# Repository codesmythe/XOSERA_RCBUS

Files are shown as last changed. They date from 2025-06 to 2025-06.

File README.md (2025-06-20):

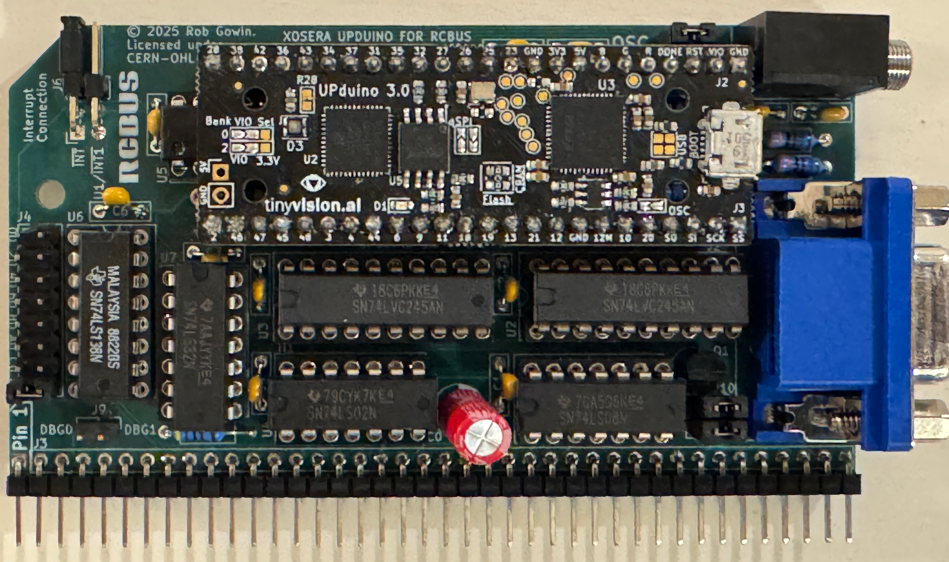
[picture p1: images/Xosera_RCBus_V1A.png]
Xosera RCBus V1A


[Xosera](https://github.com/XarkLabs/Xosera) is an FPGA based "retro"
graphics adapter created by @Xark.  Check out the link to see all of
its features (which are summarized in the image below). Xosera was
originally designed for the rosco_m68k single board computer and the
bus interface for that board. But, Xosera features a simple 8-bit data
bus with a few control signals.  So, this project is a "port" of
Xosera to the [RCBus](https://smallcomputercentral.com/rcbus/) bus
interface. 

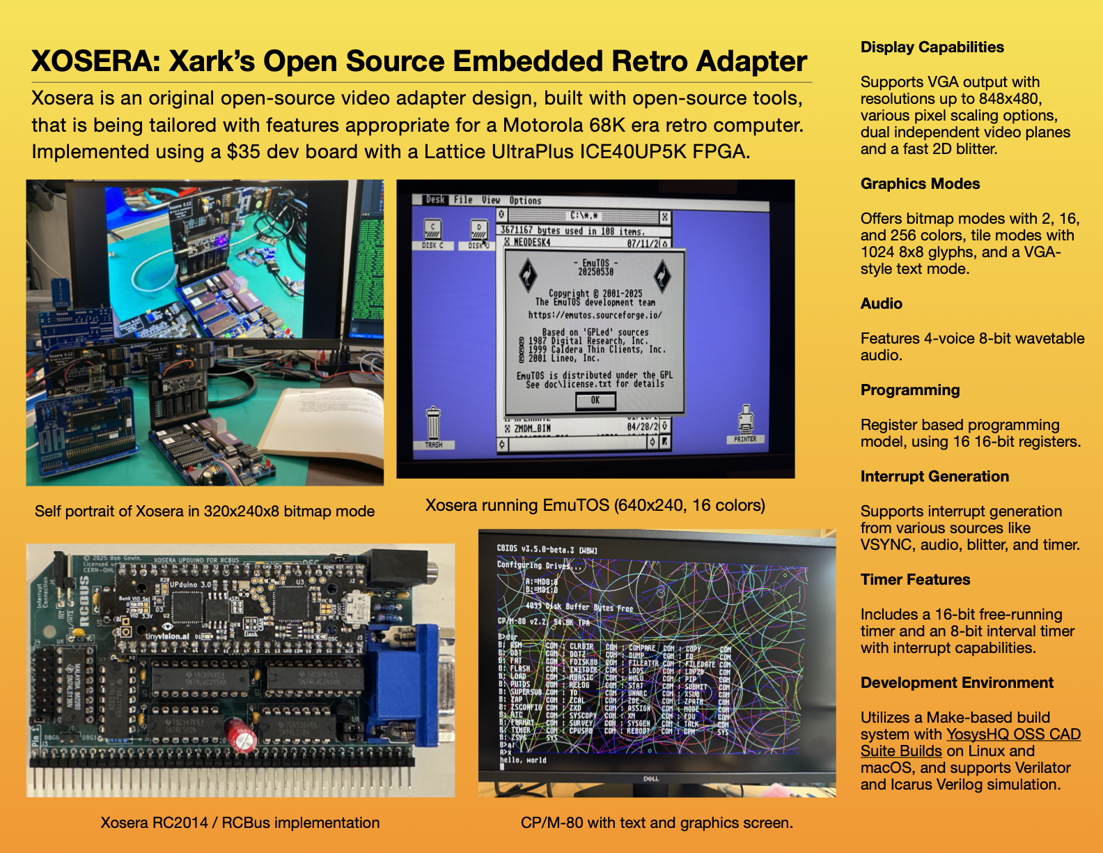
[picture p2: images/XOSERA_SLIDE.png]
Xosera Slide


## Table of Contents
* [Hardware Documentation](#hardware-documentation)
  * [Schematic](#schematic)
  * [Connectors](#connectors)
  * [Jumpers](#jumpers)
  * [Bill of Materials](#bill-of-materials)
* [Programming the FPGA](#progamming-the-fpga)
* [Acknowledgements](#acknowledgements)

## Hardware Documentation

### Schematic

This four layer board was created using [Kicad](https://www.kicad.org) version 8.0.

Click the image below to download a PDF version of the schematic.

Schematic

### Connectors

| Reference | Comment |
| --- | --- |
| J3 | 40-pin RCBus connector |
| J5 | Female VGA monitor connector |
| J11 | Audio Jack |

### Jumpers

| Reference | | Description | Comment |
| --- | --- | --- | --- |
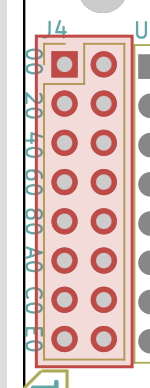
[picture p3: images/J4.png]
J4
| J4 |  | I/O Address decode | The J4 jumper block controls where in the Z80 I/O space the XOSERA_RCBUS board will appear. The Xosera interface requires 32 bytes of I/O addresses, and can be configured to appear at I/O addresses 0x00-0x1F, 0x20-0x3F, 0x40-0x5F, 0x60-0x7F, 0x80-0x9F, 0xA0-0xBF, 0xC0-0xDF or 0xE0-0xFF |
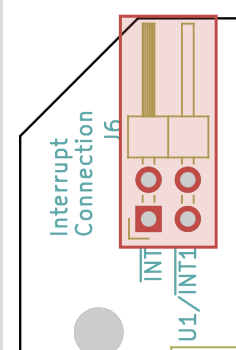
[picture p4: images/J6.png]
J6
| J6 |  | Interrupt connection to RCBus | The board can generate a single interrupt Xosera. Jumper the left two pins of J6 to use the /INT RCBus signal (pin 22) or the right two pins to use the RCBus USER1/INT1 signal (pin 37). |
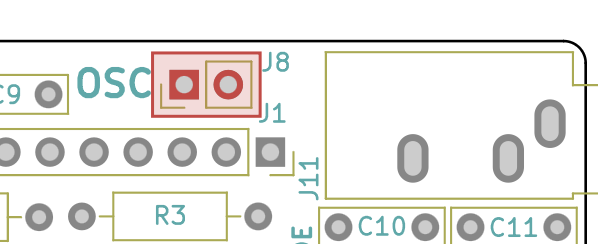
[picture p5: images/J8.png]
J8
| J8 |  | Upduino clock | This jumper must be closed for proper operation. |
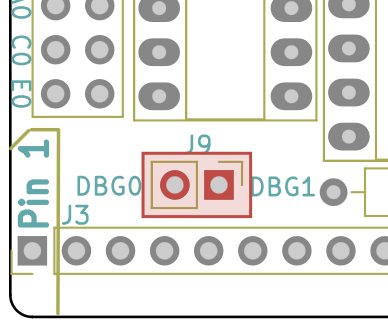
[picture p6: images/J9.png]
J9
| J9 |  | Xosera debug pin | Leave this jumper open under normal operation. |
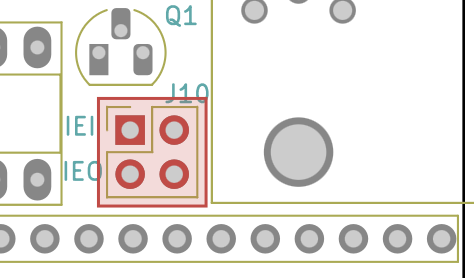
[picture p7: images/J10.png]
J10
| J10 |  | IEI/IEO signals. | Add two horizontal jumpers. These jumpers connect the XOSERA_RCBUS board to the RCBus system IEI/IEO  signals. Normally required. |

The default I/O address setting for this board is 0xA0.

## Bill of Materials (BOM)

[Text file parts list](XOSERA_RCBUS_mouser.txt) for pasting into the [Mouser BOM tool](https://www.mouser.com/Bom/CopyPaste) (login required).

Check out the [interactive BOM](https://htmlpreview.github.io/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)
for the board.

To obtain a KEMOJO PCB, download these [Gerbers](https://raw.githubusercontent.com/codesmythe/XOSERA_RCBUS/refs/heads/main/XOSERA_RCBUS_V1A.zip) for use at your preferred PCB manufacturer. I use JLCPCB.

| Component Type | Reference | Qty | Description | Part |
| --- | --- | --- | --- | --- |
| FPGA Dev Board | (Plugs into J1 & J2) | 1 | Upduino 3.1 low cost Lattice iCE40 FPGA board | Purchase from [TinyVision.ai](https://tinyvision.ai/products/fpga-development-board-upduino-v3-1) or [Tindie](https://www.tindie.com/products/tinyvision_ai/upduino-v31-low-cost-lattice-ice40-fpga-board/?pt=ac_prod_search) |
| Capacitor | C0 | 1 | 47uF, Electrolytic, 2.5mm Pitch | Mouser [710-860020673013](https://www.mouser.com/ProductDetail/710-860020673013) |
| Capacitor | C1-C9 | 9 | 0.1 uF, MLCC, 5 mm Pitch | Mouser [594-K104K15X7RF5TH5](https://www.mouser.com/ProductDetail/594-K104K15X7RF5TH5) |
| Capacitor | C10,C11 | 2 | 4700pF, MLCC, 5 mm Pitch | Mouser [594-K472K10X7RF5UH5](https://www.mouser.com/ProductDetail/594-K472K10X7RF5UH5) |
| Diode | D1 | 1 | 1N5817 | Mouser [511-1N5817](https://www.mouser.com/ProductDetail/511-1N5817) |
| Socket | J1,J2 | 2 | 1x24 female pin socket | Mouser [517-929850-01-26-RA](https://www.mouser.com/ProductDetail/517-929850-01-26-RA) |
| Connector | J3 | 1 | 1x40 right angle pin header | Mouser [710-61304011021](https://www.mouser.com/ProductDetail/710-61304011021) |
| Jumper Block | J4 | 1 | 2x8 straight pin header | Mouser [200-TSW10807TD](https://www.mouser.com/ProductDetail/200-TSW10807TD) |
| Connector | J5 | 1 | Female VGA connector | Mouser [523-7HDE15SD1CH4FVGA](https://www.mouser.com/ProductDetail/523-7HDE15SD1CH4FVGA) |
| Jumper Block | J6 | 1 | 2x2 right angle pin header | Mouser [710-61300421021](https://www.mouser.com/ProductDetail/710-61300421021) |
| Jumper | J8,J9 | 2 | 1x2 straight pin header | Mouser [571-5-146268-1](https://www.mouser.com/ProductDetail/571-5-146268-1) |
| Jumper Block | J10 | 1 | 2x2 straight pin header | Mouser [737-PH2-04-UA](https://www.mouser.com/ProductDetail/737-PH2-04-UA) |
| Connector | J11 | 1 | 3-pin Audio Jack, no switches | Mouser [SJ1-3533NG](https://www.mouser.com/ProductDetail/SJ1-3533NG) |
| Transistor | Q1 | 1 | 2N7000  MOSFET in TO92 | Mouser [512-2N7000](https://www.mouser.com/ProductDetail/512-2N7000) |
| Resistor | R1,R2,R3 | 3 | 470 ohm, axial, 1% tolerance, 1/4 W | Mouser [603-MFR-25FTF52-470R](https://www.mouser.com/ProductDetail/603-MFR-25FTF52-470R) |
| Resistor | R4,R5,R6 | 3 | 1K ohm, axial, 1% tolerance, 1/4 W | Mouser [603-MFR-25FTF52-1K](https://www.mouser.com/ProductDetail/603-MFR-25FTF52-1K) |
| Resistor | R7,R8,R9 | 3 | 2.2K ohm, axial, 1% tolerance, 1/4 W | Mouser [603-MFR-25FTF52-2K2](https://www.mouser.com/ProductDetail/603-MFR-25FTF52-2K2) |
| Resistor | R10,R11 | 2 | 47 ohm, axial, 1% tolerance, 1/4 W | Mouser [603-MFR-25FTF52-47R](https://www.mouser.com/ProductDetail/603-MFR-25FTF52-47R) |
| Resistor | R12,R13,R14,R17 |  4 | 4.7K ohm, axial, 1% tolerance, 1/4 W | Mouser [603-MFR-25FTF52-4K7](https://www.mouser.com/ProductDetail/603-MFR-25FTF52-4K7) |
| Resistor | R15,R16 | 2 | 3.3K ohm, axial, 1% tolerance, 1/4 W | Mouser [603-MFR-25FRF52-3K3](https://www.mouser.com/ProductDetail/603-MFR-25FRF52-3K3) |
| Integrated Circuit | U1 | 1 | 74LS08 quad 2-input AND in 14-pin DIP | Mouser [595-SN74LS08N](https://www.mouser.com/ProductDetail/595-SN74LS08N) |
| Integrated Circuit | U2,U3 | 2 | 74LVC245 octal bus transceiver in 20-pin DIP | Mouser [595-SN74LVC245ANE4](https://www.mouser.com/ProductDetail/595-SN74LVC245ANE4) |
| Integrated Circuit | U4 | 1 | 74LS02 quad 2-pin NOR in 14-pin DIP | Mouser [595-SN74LS02N](https://www.mouser.com/ProductDetail/595-SN74LS02N) |
| Integrated Circuit | U5 | 1 | 74LS74 dual D flip flops in 14-pin DIP | Mouser [595-SN74LS74ANE4](https://www.mouser.com/ProductDetail/595-SN74LS74ANE4) |
| Integrated Circuit | U6 | 1 | 74LS138 3 to 8 decoder in 16-pin DIP | Mouser [595-SN74LS138N](https://www.mouser.com/ProductDetail/595-SN74LS138N) |
| Integrated Circuit | U7 | 1 | 74LS32 quad 2-pin OR in 14-pin DIP | Mouser [595-SN74LS32N](https://www.mouser.com/ProductDetail/595-SN74LS32N) |
| Socket | Sockets for U1,U4,U5,U7 | 4 | 14-pin DIP socket | Mouser [571-1-2199298-3](https://www.mouser.com/ProductDetail/571-1-2199298-3) |
| Socket | Sockets for U2,U3 | 2 | 20-pin DIP socket | Mouser [571-1-2199298-6](https://www.mouser.com/ProductDetail/571-1-2199298-6) |
| Socket | Socket for U6 | 1 | 16-pin DIP socket | Mouser [571-1-2199298-4](https://www.mouser.com/ProductDetail/571-1-2199298-4) |

## Programming the FPGA

The FPGA development board used by the Xosera graphics adapter is the [Upduino 3.1](https://tinyvision.ai/products/fpga-development-board-upduino-v3-1), which hosts a Lattice ICE40UP5K FPGA.

First, you will need the binary for the tool that actually does the programming, which is `iceprog.` This is available from the OSS CAD Suite tools. Download the Suite for your platform (Mac, Linux or Windows) from [here](https://github.com/YosysHQ/oss-cad-suite-build/releases).

Next, you will need the Xosera bitstream to load into the FPGA on the Upduino board. The bitstream is available 
[here](https://github.com/XarkLabs/Xosera/blob/develop/xosera_gateware/xosera_board_vga.bin). (Click on the "Download raw file" button third from right.). This file should be saved as `xosera_board_vga.bin`. 

For Windows, you will need the correct USB drivers. Installing those drivers is beyond the scope of this document, but relevant information can be found [here](https://github.com/FPGAwars/libftdi-cross-builder/wiki#driver-installation).

Then for any of the three platforms, at a command line prompt, use the `iceprog` (or `iceprog.exe`) program from the ISS Cad Suite to send the bitstream to the FPGA:

    $ iceprog -d i:0x0403:0x6014 xosera_board_vga.bin

*to be expanded*

## Acknowledgements

@Xark for creating the excellent Xosera project.

@roscopeco for designing the rosco_m68k Xosera [host board](https://github.com/rosco-m68k/hardware-projects/tree/master/xosera), from which I cribbed some of this design.

@lfantoniosi for his [tn_vdp](https://github.com/lfantoniosi/tn_vdp) project, from which I also borrowed a few ideas.

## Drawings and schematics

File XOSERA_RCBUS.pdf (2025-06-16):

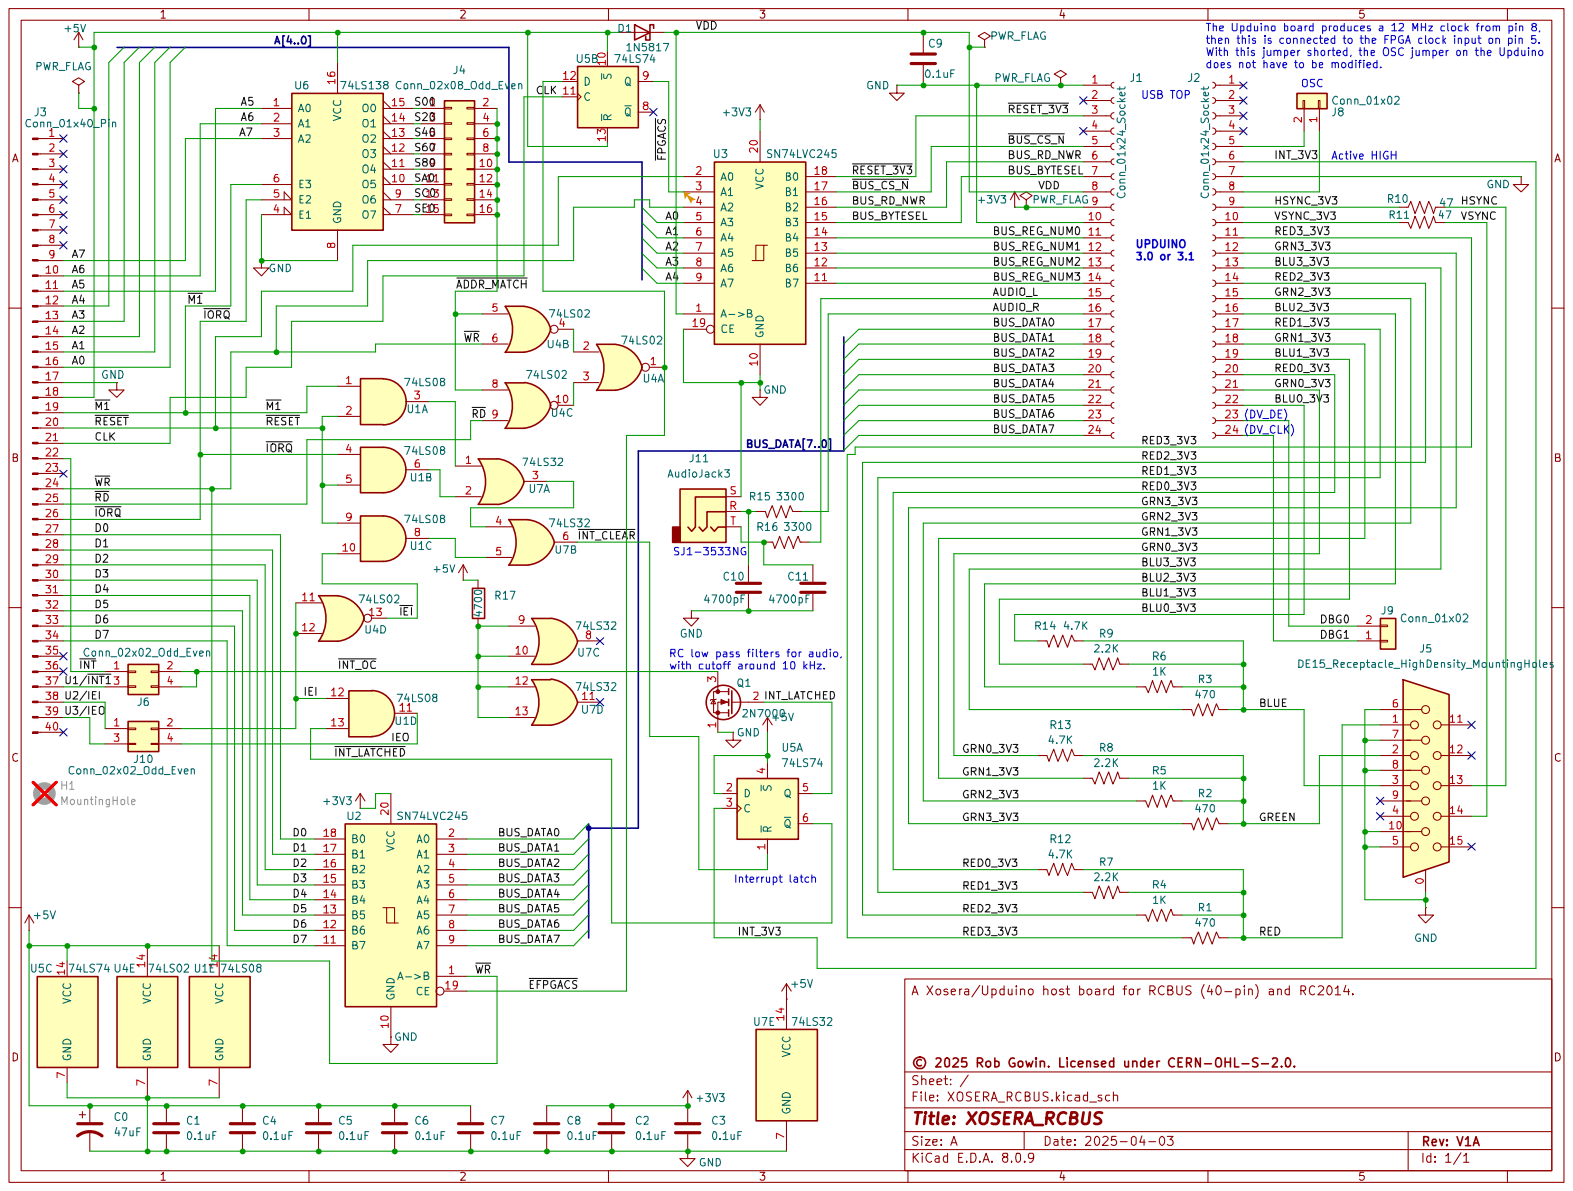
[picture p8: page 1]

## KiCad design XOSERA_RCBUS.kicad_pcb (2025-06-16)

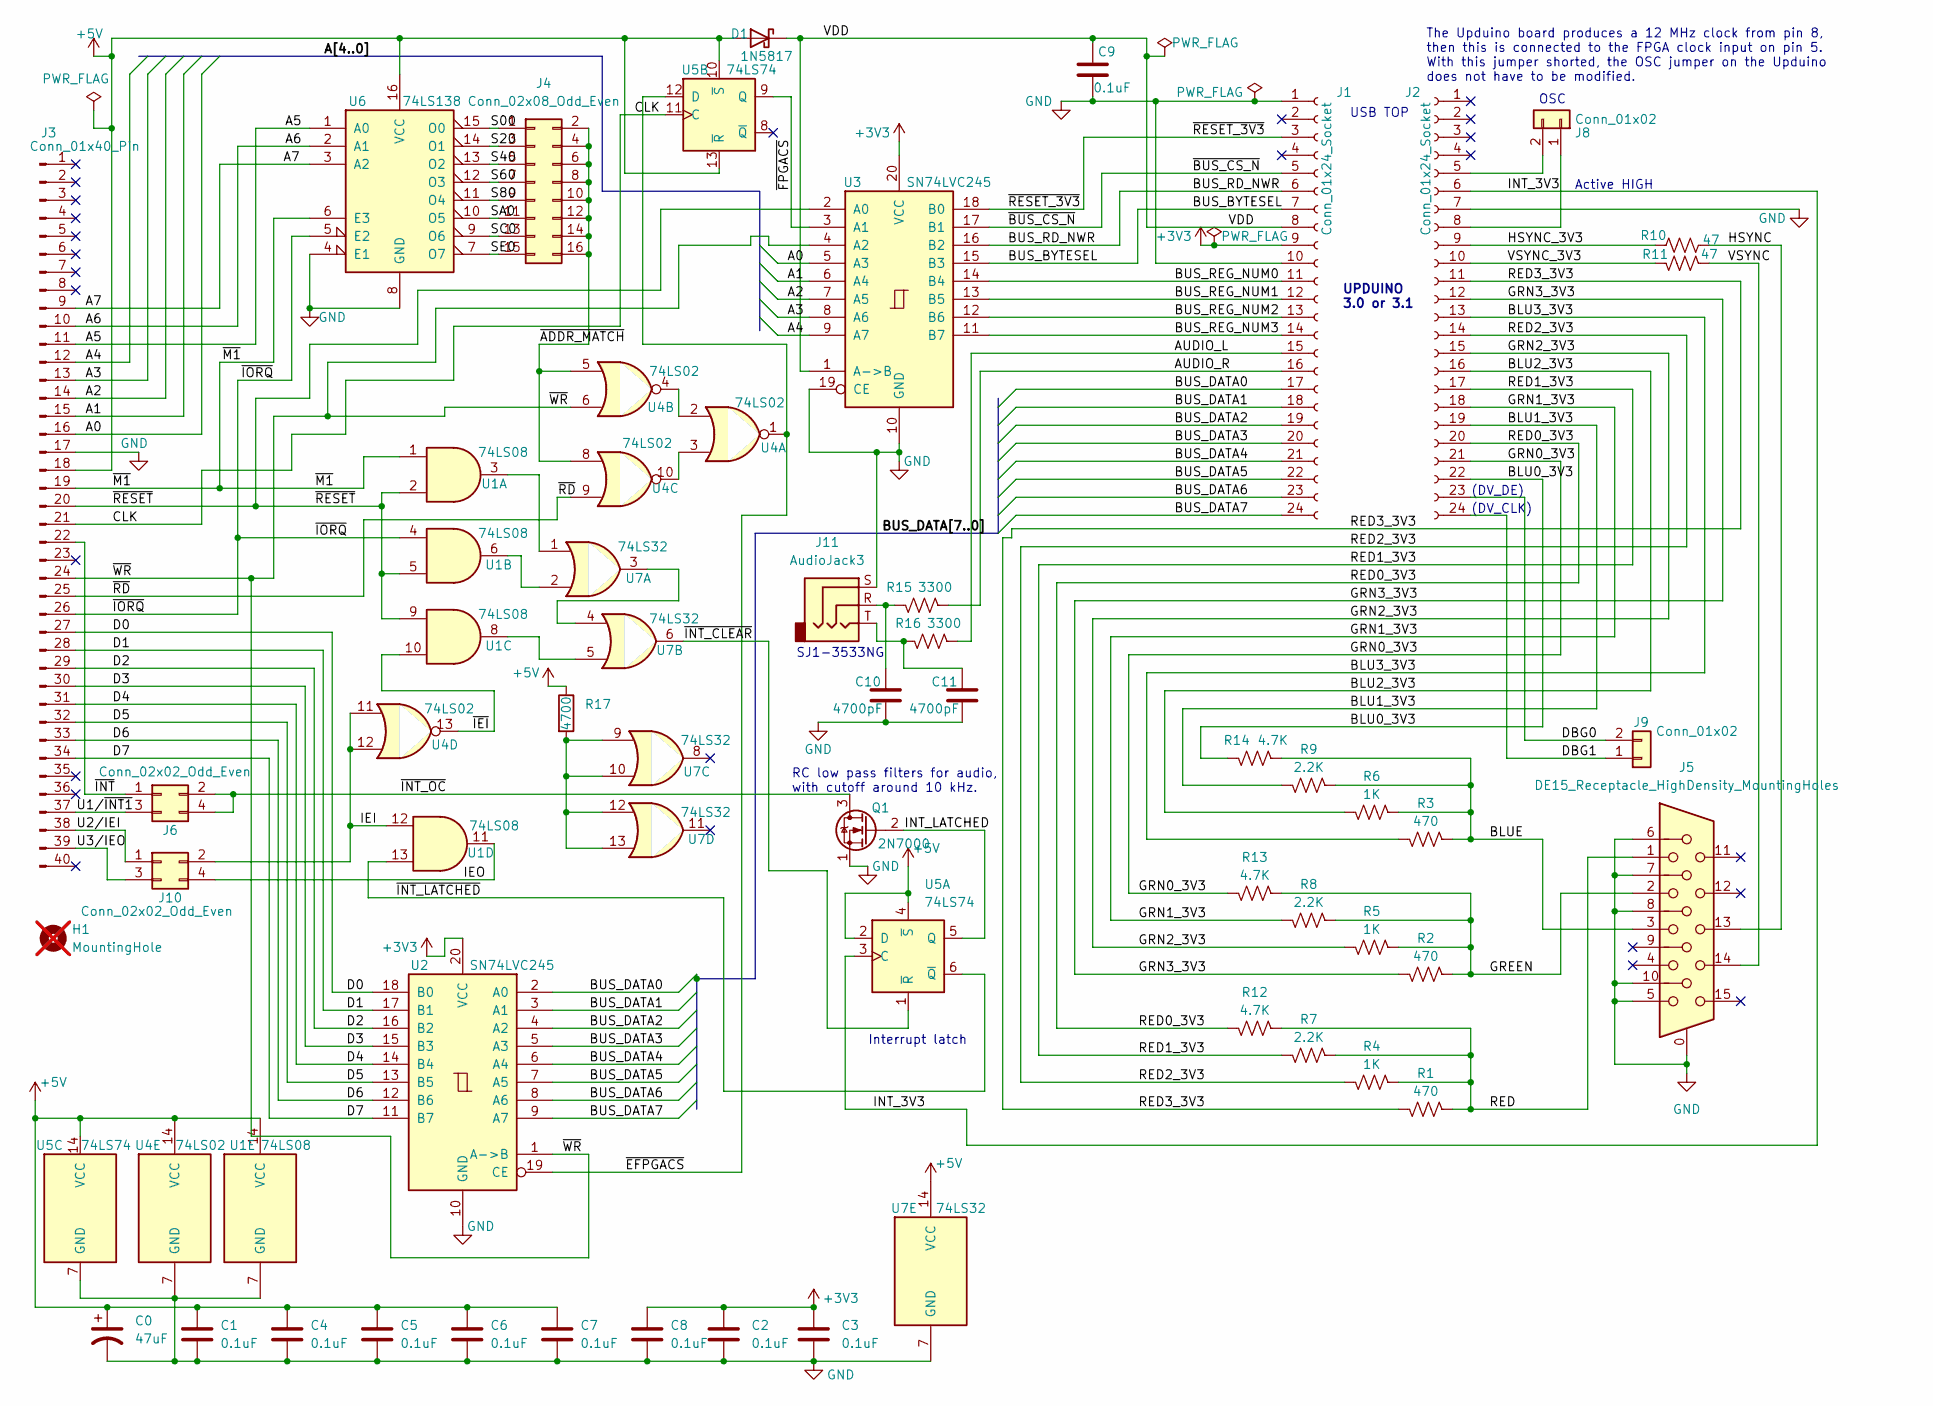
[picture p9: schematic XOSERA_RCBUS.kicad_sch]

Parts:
C0: 47uF; CP_Radial_D6.3mm_P2.50mm; PartNum00 710-860020673013
C1, C2, C3, C4, C5, C6, C7, C8, C9: 0.1uF; C_Rect_L7.0mm_W2.0mm_P5.00mm; PartNum00 594-K104K15X7RF5TH5
C10, C11: 4700pF; C_Rect_L7.0mm_W2.0mm_P5.00mm; PartNum00 594-K472K10X7RF5UH5
D1: 1N5817; D_DO-41_SOD81_P10.16mm_Horizontal; PartNum00 511-1N5817
H1: MountingHole; MountingHole_3.2mm_M3_ISO7380; not fitted
J1, J2: Conn_01x24_Socket; PinSocket_1x24_P2.54mm_Vertical; PartNum00 517-929850-01-26-RA
J3: Conn_01x40_Pin; PinHeader_1x40_P2.54mm_Vertical; PartNum00 710-61304011021
J4: Conn_02x08_Odd_Even; PinHeader_2x08_P2.54mm_Vertical; PartNum00 200-TSW10807TD
J5: DE15_Receptacle_HighDensity_MountingHoles; DSUB-15-Female_Right_Angle_VGA; PartNum00 523-7HDE15SD1CH4FVGA
J6: Conn_02x02_Odd_Even; PinHeader_2x02_P2.54mm_Horizontal; PartNum00 710-61300421021
J8, J9: Conn_01x02; PinHeader_1x02_P2.54mm_Vertical; PartNum00 571-5-146268-1
J10: Conn_02x02_Odd_Even; PinHeader_2x02_P2.54mm_Vertical; PartNum00 737-PH2-04-UA
J11: AudioJack3; Jack_3.5mm_CUI_SJ1-3533NG_Horizontal; PartNum00 SJ1-3533NG
Q1: 2N7000; TO-92_HandSolder; PartNum00 512-2N7000
R1, R2, R3: 470; R_Axial_DIN0207_L6.3mm_D2.5mm_P10.16mm_Horizontal; PartNum00 603-MFR-25FTF52-470R
R4, R5, R6: 1K; R_Axial_DIN0207_L6.3mm_D2.5mm_P10.16mm_Horizontal; PartNum00 603-MFR-25FTF52-1K
R7, R8, R9: 2.2K; R_Axial_DIN0207_L6.3mm_D2.5mm_P10.16mm_Horizontal; PartNum00 603-MFR-25FTF52-2K2
R10, R11: 47; R_Axial_DIN0207_L6.3mm_D2.5mm_P10.16mm_Horizontal; PartNum00 603-MFR-25FTF52-47R
R12, R13, R14: 4.7K; R_Axial_DIN0207_L6.3mm_D2.5mm_P10.16mm_Horizontal; PartNum00 603-MFR-25FTF52-4K7
R15, R16: 3300; R_Axial_DIN0207_L6.3mm_D2.5mm_P10.16mm_Horizontal; PartNum00 603-MFR-25FRF52-3K3
R17: 4700; R_Axial_DIN0207_L6.3mm_D2.5mm_P10.16mm_Horizontal; PartNum00 603-MFR-25FTF52-4K7
U1: 74LS08; DIP-14_W7.62mm_Socket_LongPads; PartNum00 595-SN74LS08N
U2, U3: SN74LVC245; DIP-20_W7.62mm_Socket_LongPads; PartNum00 595-SN74LVC245ANE4
U4: 74LS02; DIP-14_W7.62mm_Socket_LongPads; PartNum00 595-SN74LS02N
U5: 74LS74; DIP-14_W7.62mm_Socket_LongPads; PartNum00 595-SN74LS74ANE4
U6: 74LS138; DIP-16_W7.62mm_Socket_LongPads; PartNum00 595-SN74LS138N
U7: 74LS32; DIP-14_W7.62mm_Socket_LongPads; PartNum00 595-SN74LS32N

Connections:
+3V3: C2.1, C3.1, C8.1, J1.9, U2.20 (VCC), U3.20 (VCC)
+5V: C0.1, C1.1, C4.1, C5.1, C6.1, C7.1, D1.2 (A), J3.18, R17.1, U1.14 (VCC), U4.14 (VCC), U5.2 (D), U5.4 (~S), U5.10 (~S), U5.13 (~R), U5.14 (VCC), U6.16 (VCC), U7.14 (VCC)
/A0: J3.16, U3.5 (A3)
/A1: J3.15, U3.6 (A4)
/A2: J3.14, U3.7 (A5)
/A3: J3.13, U3.8 (A6)
/A4: J3.12, U3.9 (A7)
/A5: J3.11, U6.1 (A0)
/A6: J3.10, U6.2 (A1)
/A7: J3.9, U6.3 (A2)
/AUDIO_L: J1.15, R16.1
/AUDIO_R: J1.16, R15.1
/BLU0_3V3: J2.22, R14.2
/BLU1_3V3: J2.19, R9.2
/BLU2_3V3: J2.16, R6.2
/BLU3_3V3: J2.13, R3.2
/BLUE: J5.3, R3.1, R6.1, R9.1, R14.1
/BUS_BYTESEL: J1.7, U3.15 (B3)
/BUS_DATA0: J1.17, U2.2 (A0)
/BUS_DATA1: J1.18, U2.3 (A1)
/BUS_DATA2: J1.19, U2.4 (A2)
/BUS_DATA3: J1.20, U2.5 (A3)
/BUS_DATA4: J1.21, U2.6 (A4)
/BUS_DATA5: J1.22, U2.7 (A5)
/BUS_DATA6: J1.23, U2.8 (A6)
/BUS_DATA7: J1.24, U2.9 (A7)
/BUS_RD_NWR: J1.6, U3.16 (B2)
/BUS_REG_NUM0: J1.11, U3.14 (B4)
/BUS_REG_NUM1: J1.12, U3.13 (B5)
/BUS_REG_NUM2: J1.13, U3.12 (B6)
/BUS_REG_NUM3: J1.14, U3.11 (B7)
/CLK: J3.21, U5.11 (C)
/D0: J3.27, U2.18 (B0)
/D1: J3.28, U2.17 (B1)
/D2: J3.29, U2.16 (B2)
/D3: J3.30, U2.15 (B3)
/D4: J3.31, U2.14 (B4)
/D5: J3.32, U2.13 (B5)
/D6: J3.33, U2.12 (B6)
/D7: J3.34, U2.11 (B7)
/DBG0: J2.23, J9.2
/DBG1: J2.24, J9.1
/GREEN: J5.2, R2.1, R5.1, R8.1, R13.1
/GRN0_3V3: J2.21, R13.2
/GRN1_3V3: J2.18, R8.2
/GRN2_3V3: J2.15, R5.2
/GRN3_3V3: J2.12, R2.2
/HSYNC: J5.13, R10.2
/HSYNC_3V3: J2.9, R10.1
/IEI: J10.2, U1.12, U4.11, U4.12
/IEO: J10.4, U1.11
/INT_3V3: J2.6, U5.3 (C)
/INT_LATCHED: Q1.2 (G), U5.5 (Q)
/RED: J5.1, R1.1, R4.1, R7.1, R12.1
/RED0_3V3: J2.20, R12.2
/RED1_3V3: J2.17, R7.2
/RED2_3V3: J2.14, R4.2
/RED3_3V3: J2.11, R1.2
/S00: J4.1, U6.15 (O0)
/S20: J4.3, U6.14 (O1)
/S40: J4.5, U6.13 (O2)
/S60: J4.7, U6.12 (O3)
/S80: J4.9, U6.11 (O4)
/SA0: J4.11, U6.10 (O5)
/SC0: J4.13, U6.9 (O6)
/SE0: J4.15, U6.7 (O7)
/U1/~INT1: J3.37, J6.3
/U2/IEI: J3.38, J10.1
/U3/IEO: J3.39, J10.3
/VDD: C9.1, D1.1 (K), J1.8, U3.1 (A->B)
/VSYNC: J5.14, R11.1
/VSYNC_3V3: J2.10, R11.2
/~ADDR_MATCH: J4.2, J4.4, J4.6, J4.8, J4.10, J4.12, J4.14, J4.16, U4.5, U4.8
/~BUS_CS_N: J1.5, U3.17 (B1)
/~EFPGACS: U2.19 (CE), U4.1, U5.12 (D)
/~FPGACS: U3.3 (A1), U5.9 (Q)
/~IEI: U1.10, U4.13
/~INT_CLEAR: U5.1 (~R), U7.6
/~INT_LATCHED: U1.13, U5.6 (~Q)
/~INT_OC: J6.2, J6.4, Q1.3 (D)
/~INT: J3.22, J6.1
/~IORQ: J3.26, U1.4, U6.5 (E2)
/~M1: J3.19, U1.1, U6.6 (E3)
/~RD: J3.25, U4.9
/~RESET_3V3: J1.3, U3.18 (B0)
/~RESET: J3.20, U1.2, U1.5, U1.9, U3.2 (A0)
/~WR: J3.24, U2.1 (A->B), U3.4 (A2), U4.6
GND: C0.2, C1.2, C2.2, C3.2, C4.2, C5.2, C6.2, C7.2, C8.2, C9.2, C10.2, C11.2, J1.1, J1.10, J2.7, J3.17, J5.0, J5.5, J5.6, J5.7, J5.8, J5.10, J11.S, Q1.1 (S), U1.7 (GND), U2.10 (GND), U3.10 (GND), U3.19 (CE), U4.7 (GND), U5.7 (GND), U6.4 (E1), U6.8 (GND), U7.7 (GND)
unnamed: C10.1, J11.R, R15.2
unnamed: C11.1, J11.T, R16.2
unnamed: J2.5, J8.2
unnamed: J2.8, J8.1
unnamed: R17.2, U7.9, U7.10, U7.12, U7.13
unnamed: U1.3, U7.1
unnamed: U1.6, U7.2
unnamed: U1.8, U7.5
unnamed: U4.2, U4.4
unnamed: U4.3, U4.10
unnamed: U7.3, U7.4

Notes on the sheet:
USB TOP
(DV_DE)
Interrupt latch
(DV_CLK)
RC low pass filters for audio, with cutoff around 10 kHz.
UPDUINO 3.0 or 3.1
Active HIGH
OSC
SJ1-3533NG
The Upduino board produces a 12 MHz clock from pin 8, then this is connected to the FPGA clock input on pin 5. With this jumper shorted, the OSC jumper on the Upduino does not have to be modified.

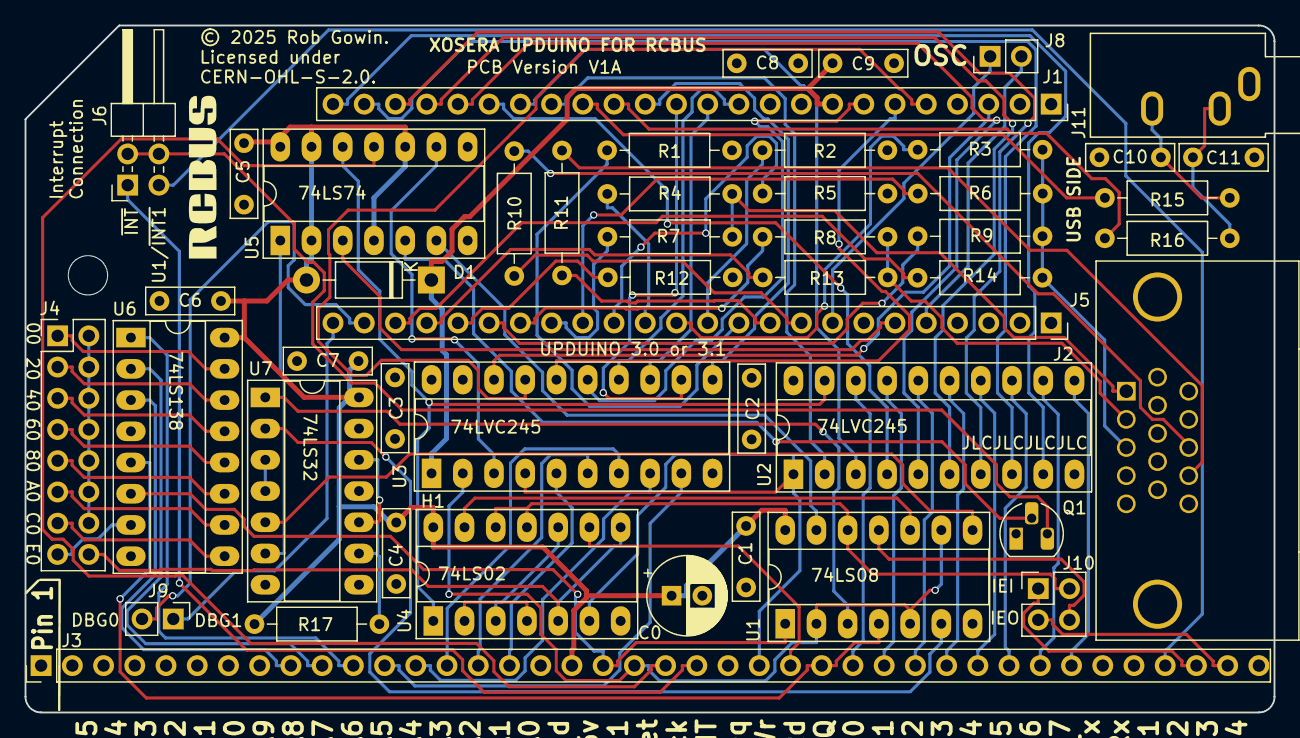
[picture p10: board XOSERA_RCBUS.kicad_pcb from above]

Board: 4 copper layers, 101.6 x 55.9 mm, 49 parts (0 on the bottom side), 99 nets.

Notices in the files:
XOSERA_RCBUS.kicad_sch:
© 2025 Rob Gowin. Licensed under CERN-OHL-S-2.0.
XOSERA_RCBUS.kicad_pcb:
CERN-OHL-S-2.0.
